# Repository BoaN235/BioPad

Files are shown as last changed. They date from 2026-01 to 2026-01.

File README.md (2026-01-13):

# BioPad
A 12 key macropad with a oled display and 5 LEDS uses KMK firmware. It is supposed to be a used during work to 

## Features
- 128x32 OLED Display
- KMK
- 12 Keys
- 4 Layers Currently
- 5 LEDS

## Cad Model
It fits with 4 M3 Bolts and it has 4 M1 Bolts to hold the pcb down. 
It has 3 parts the bottem the layer blocking the keys and top. 



## PCB
My PCB is 100mm by 58mm. I made it in Kicad



## Firmware
I am using KMK to be able to hotswitch it to whatever people need.
There is currently 3 layers Apps Vscode and Zoom. Each of those has hotkeys related to each app. The Apps layer types in Windows + R and adds the name of a website or app.

## BOM
Evreything I am gonna use to make it if it isen't in the kit I have it myself

- 12x Cherry MX Switches
- 12x DSA Keycaps
- 4x M3x5x4 Heatset inserts
- 4x M3x16mm SHCS Bolts
- 4x M1x5x4 Heatset inserts
- 4x M1x16mm SHCS Bolts
- 12x 1N4148 DO-35 Diodes.
- 5x WS2812B LEDs
- 1x 0.91" 128x32 OLED Display
- 1x XIAO RP2040
- 1x Case (3 printed parts I can print it myself)

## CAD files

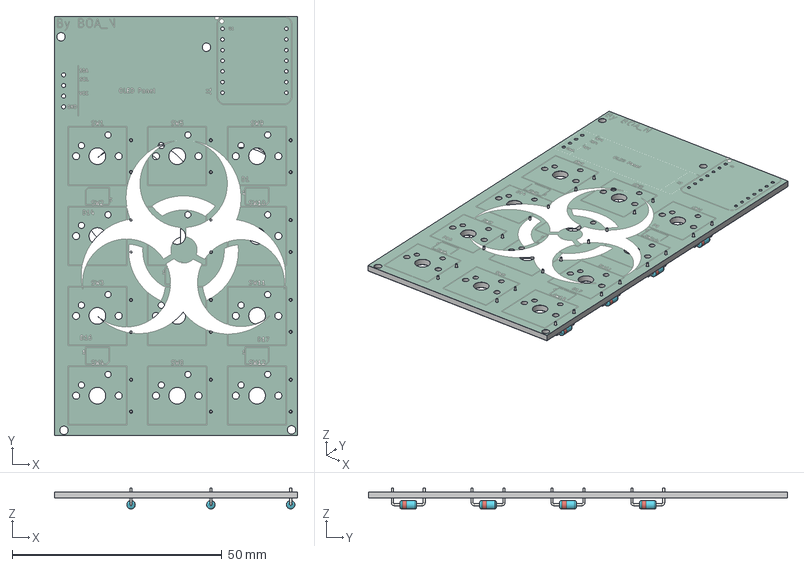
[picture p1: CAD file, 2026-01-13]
CAD/BioPad.step
58.0 x 100.0 x 5.01 mm
D_DO-35_SOD27_P7.62mm_Horizontal x 12
BioPad_silkscreen x 2
BioPad_soldermask x 2
BioPad_PCB

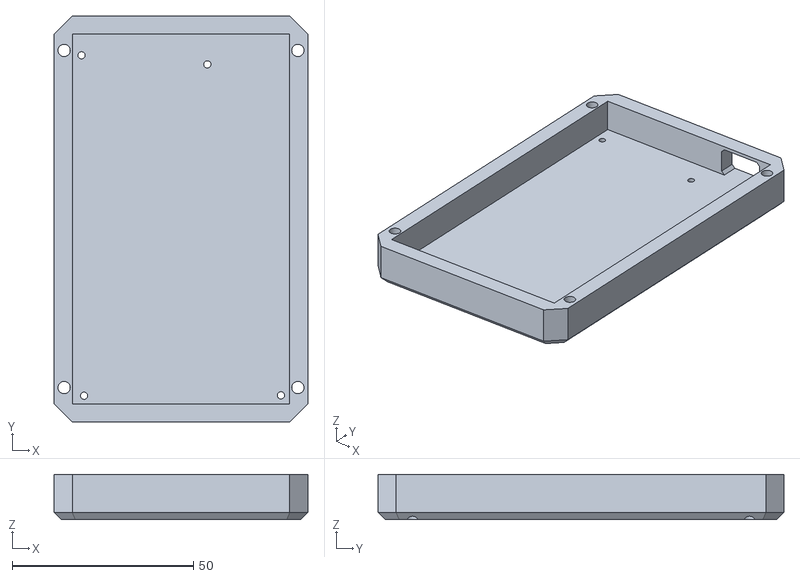
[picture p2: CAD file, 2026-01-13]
CAD/BaseHackPad.stl
70.0 x 112.0 x 12.5

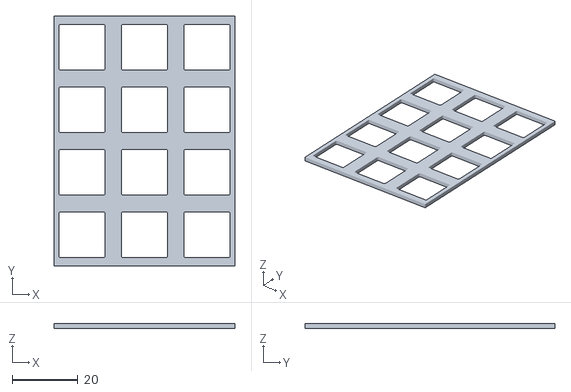
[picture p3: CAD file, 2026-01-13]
CAD/LayerHackPad.stl
55.1 x 76.2 x 1.50

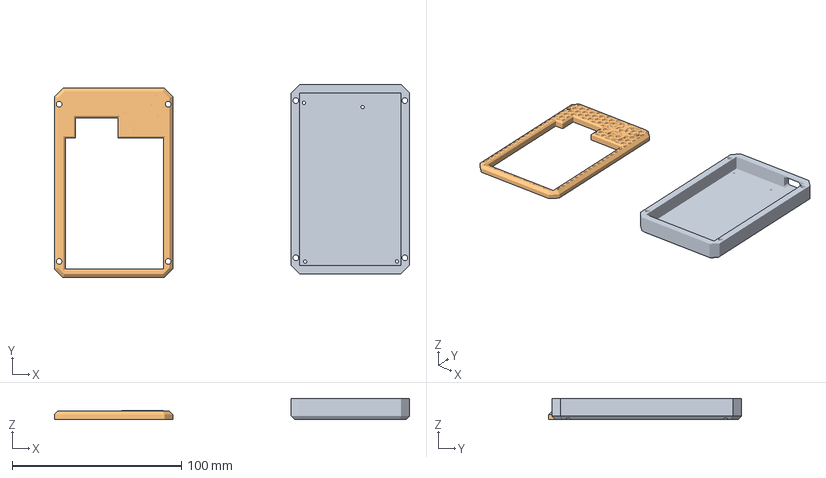
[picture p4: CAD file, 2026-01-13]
CAD/TopHackPad.3mf
210.0 x 114.1 x 12.5 mm
BaseHackPad.stl
TopHackPad.stl

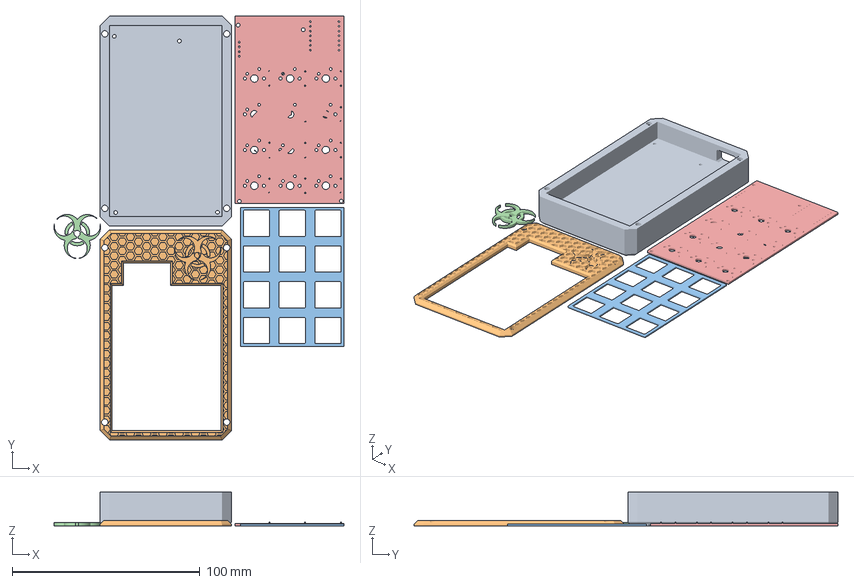
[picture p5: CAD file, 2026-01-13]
CAD/HackPad.3mf
154.5 x 226.0 x 18.0 mm
BaseHackPad.stl
TopHackPad.stl
LayerHackPad.stl
BioMedel.stl
PCBMesh.stl_B

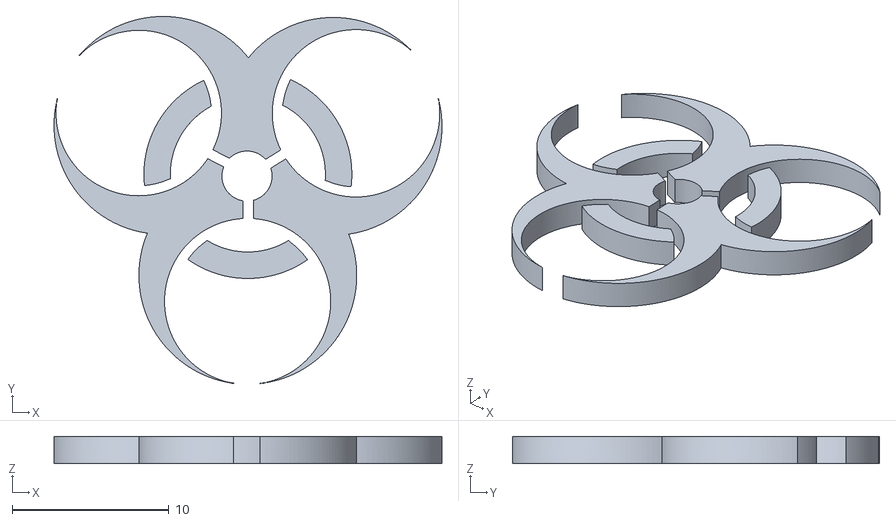
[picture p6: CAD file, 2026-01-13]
CAD/BioMedel.stl
24.8 x 23.4 x 1.75

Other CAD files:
CAD/PCBMesh.stl
CAD/TopHackPad.stl

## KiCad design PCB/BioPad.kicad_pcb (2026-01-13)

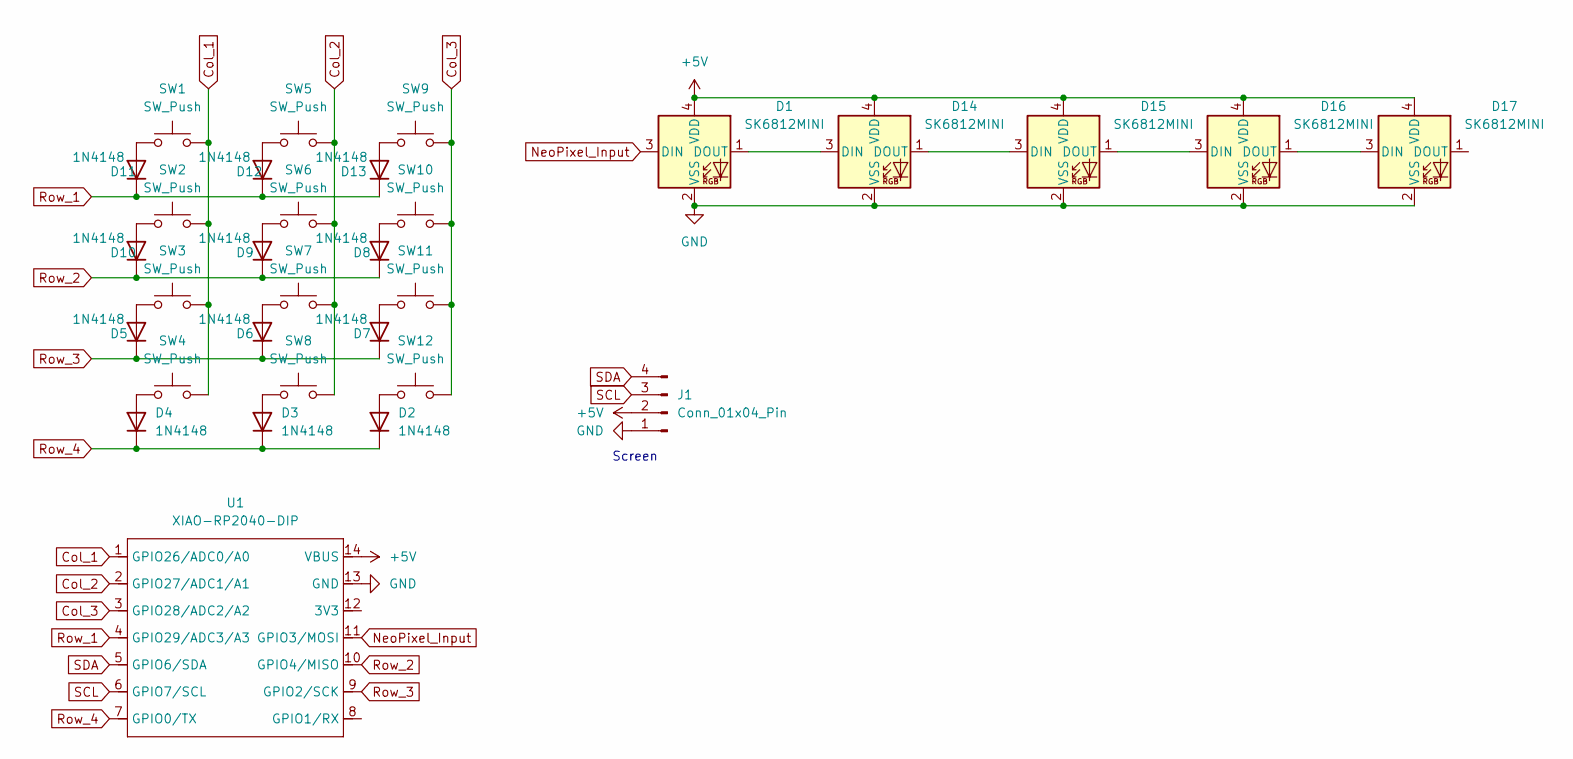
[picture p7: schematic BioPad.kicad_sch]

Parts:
D1, D14, D15, D16, D17: SK6812MINI; LED_SK6812MINI_PLCC4_3.5x3.5mm_P1.75mm
D2, D3, D4, D5, D6, D7, D8, D9, D10, D11, D12, D13: 1N4148; D_DO-35_SOD27_P7.62mm_Horizontal
J1: Conn_01x04_Pin; SSD1306-0.91-OLED-4pin-128x32
SW1, SW2, SW3, SW4, SW5, SW6, SW7, SW8, SW9, SW10, SW11, SW12: SW_Push; SW_Cherry_MX_1.00u_PCB
U1: XIAO-RP2040-DIP

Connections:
+5V: D1.4 (VDD), D14.4 (VDD), D15.4 (VDD), D16.4 (VDD), D17.4 (VDD), J1.2, U1.14 (VBUS)
Col_1: SW1.2, SW2.2, SW3.2, SW4.2, U1.1 (GPIO26/ADC0/A0)
Col_2: SW5.2, SW6.2, SW7.2, SW8.2, U1.2 (GPIO27/ADC1/A1)
Col_3: SW9.2, SW10.2, SW11.2, SW12.2, U1.3 (GPIO28/ADC2/A2)
GND: D1.2 (VSS), D14.2 (VSS), D15.2 (VSS), D16.2 (VSS), D17.2 (VSS), J1.1, U1.13 (GND)
NeoPixel_Input: D1.3 (DIN), U1.11 (GPIO3/MOSI)
unnamed: D1.1 (DOUT), D14.3 (DIN)
unnamed: D2.2 (A), SW12.1
unnamed: D3.2 (A), SW8.1
unnamed: D4.2 (A), SW4.1
unnamed: D5.2 (A), SW3.1
unnamed: D6.2 (A), SW7.1
unnamed: D7.2 (A), SW11.1
unnamed: D8.2 (A), SW10.1
unnamed: D9.2 (A), SW6.1
unnamed: D10.2 (A), SW2.1
unnamed: D11.2 (A), SW1.1
unnamed: D12.2 (A), SW5.1
unnamed: D13.2 (A), SW9.1
unnamed: D14.1 (DOUT), D15.3 (DIN)
unnamed: D15.1 (DOUT), D16.3 (DIN)
unnamed: D16.1 (DOUT), D17.3 (DIN)
Row_1: D11.1 (K), D12.1 (K), D13.1 (K), U1.4 (GPIO29/ADC3/A3)
Row_2: D8.1 (K), D9.1 (K), D10.1 (K), U1.10 (GPIO4/MISO)
Row_3: D5.1 (K), D6.1 (K), D7.1 (K), U1.9 (GPIO2/SCK)
Row_4: D2.1 (K), D3.1 (K), D4.1 (K), U1.7 (GPIO0/TX)
SCL: J1.3, U1.6 (GPIO7/SCL)
SDA: J1.4, U1.5 (GPIO6/SDA)

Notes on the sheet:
Screen

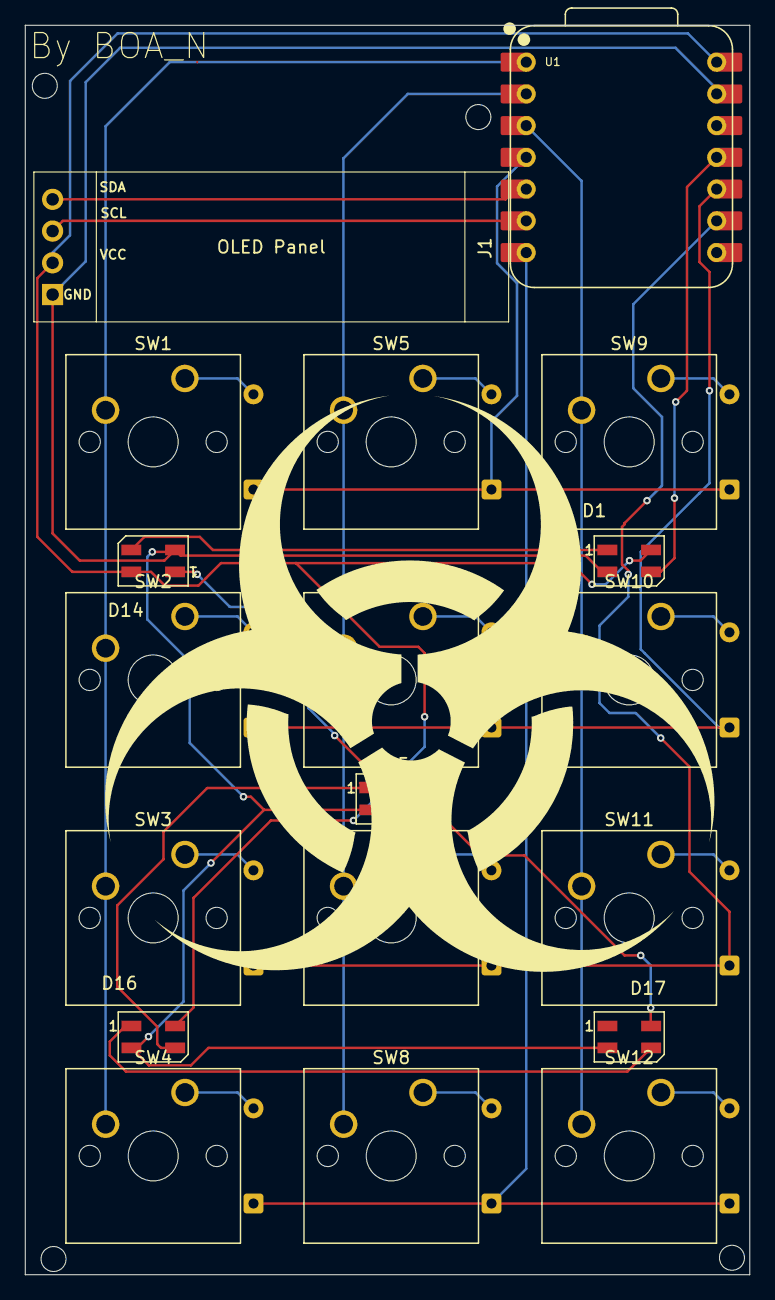
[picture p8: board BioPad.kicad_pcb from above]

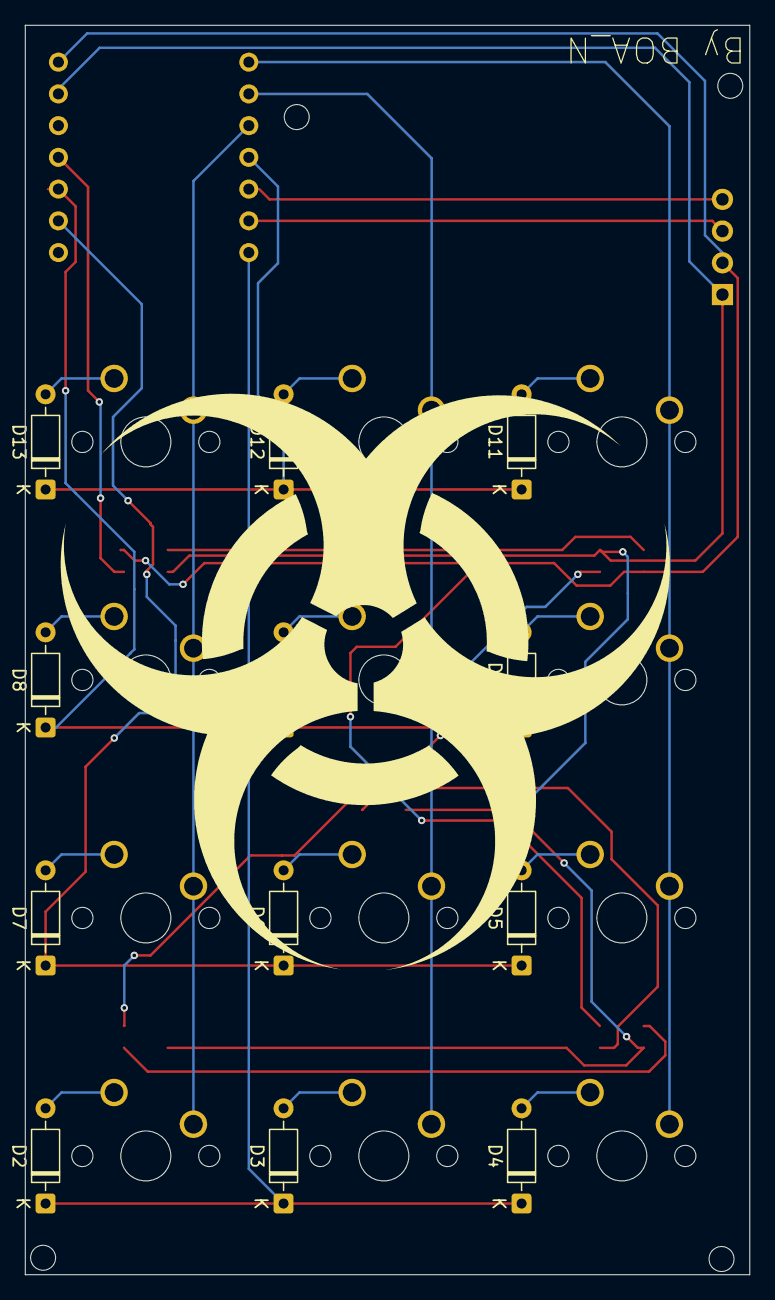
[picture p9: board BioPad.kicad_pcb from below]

Board: 2 copper layers, 58.0 x 100.0 mm, 31 parts (12 on the bottom side), 28 nets.

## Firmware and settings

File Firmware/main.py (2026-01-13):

print("Starting")

import board
import busio

from kmk.kmk_keyboard import KMKKeyboard
from kmk.keys import KC
from kmk.scanners import DiodeOrientation
from kmk.modules.layers import Layers
from kmk.modules.macros import Macros

from kmk.extensions.display import Display
from kmk.extensions.display.ssd1306 import SSD1306

keyboard = KMKKeyboard()

keyboard.col_pins = (board.GP26, board.GP27, board.GP28)
keyboard.row_pins = (board.GP29, board.GP4, board.GP2, board.GP0)
keyboard.diode_orientation = DiodeOrientation.COL2ROW


layers = Layers()
macros = Macros()

keyboard.modules.append(layers)
keyboard.modules.append(macros)


i2c = busio.I2C(board.GP7, board.GP6)

oled = SSD1306(
    i2c=i2c,
    width=128,
    height=32,
    rotation=0,
)

display = Display(
    display=oled,
    width=128,
    height=32,
    brightness=1,
)

keyboard.extensions.append(display)


LAYER_NAMES = {
    0: "BASE",
    1: "APPS",
    2: "ZOOM",
    3: "VSCODE",
}

def draw_layer(oled, layer):
    oled.fill(0)
    oled.text("Reprint", 0, 0, 1)
    oled.text(LAYER_NAMES.get(layer, "???"), 0, 16, 1)
    oled.show()

def on_layer_change(layer):
    draw_layer(oled, layer)

layers.after_layer_change = on_layer_change
draw_layer(oled, 0)


macros.macros = {
    # App Launch 
    "GMAIL": [KC.LGUI, KC.R, "https://mail.google.com", KC.ENTER],
    "CAL":   [KC.LGUI, KC.R, "https://calendar.google.com", KC.ENTER],
    "GIT":   [KC.LGUI, KC.R, "https://github.com", KC.ENTER],
    "JIRA":  [KC.LGUI, KC.R, "https://jira.atlassian.com", KC.ENTER],
    "ZOOM":  [KC.LGUI, KC.R, "zoom", KC.ENTER],
    "SLACK": [KC.LGUI, KC.R, "slack", KC.ENTER],
    "CODE":  [KC.LGUI, KC.R, "code", KC.ENTER],
    "EXP":   [KC.LGUI, KC.E],
    "LOCK":  [KC.LGUI, KC.L],

    # Zoom Controls
    "ZM_MUTE":  [KC.LALT, KC.A],
    "ZM_VIDEO": [KC.LALT, KC.V],
    "ZM_SHARE": [KC.LALT, KC.S],
    "ZM_FOCUS": [KC.LCTRL, KC.LALT, KC.LSHIFT],

    # VS Code
    "VS_CMD":   [KC.LCTRL, KC.LSHIFT, KC.P],
    "VS_OPEN":  [KC.LCTRL, KC.P],
    "VS_TERM":  [KC.LCTRL, KC.GRAVE],
    "VS_SAVE":  [KC.LCTRL, KC.S],
    "VS_FIND":  [KC.LCTRL, KC.F],
    "VS_REPL":  [KC.LCTRL, KC.H],
    "VS_FMT":   [KC.LSHIFT, KC.LALT, KC.F],
}


MO_APPS   = KC.MO(1)
MO_ZOOM   = KC.MO(2)
MO_VSCODE = KC.MO(3)

keyboard.keymap = [
    # Layer 0 — BASE
    [
        KC.A,       KC.B,       KC.C,
        KC.D,       KC.E,       KC.F,
        KC.G,       KC.H,       KC.I,
        MO_APPS,    MO_ZOOM,    MO_VSCODE,
    ],

    # Layer 1 — APPS
    [
        KC.MACRO("GMAIL"), KC.MACRO("CAL"),   KC.MACRO("GIT"),
        KC.MACRO("JIRA"),  KC.MACRO("ZOOM"),  KC.MACRO("SLACK"),
        KC.MACRO("CODE"),  KC.MACRO("EXP"),   KC.NO,
        KC.MACRO("LOCK"),  KC.NO,             KC.NO,
    ],

    # Layer 2 — ZOOM
    [
        KC.MACRO("ZM_MUTE"),  KC.MACRO("ZM_VIDEO"), KC.MACRO("ZM_SHARE"),
        KC.MACRO("ZM_FOCUS"), KC.NO,                KC.NO,
        KC.NO,                KC.NO,                KC.NO,
        KC.MO(0),             KC.NO,                KC.NO,
    ],

    # Layer 3 — VSCODE
    [
        KC.MACRO("VS_CMD"),  KC.MACRO("VS_OPEN"), KC.MACRO("VS_TERM"),
        KC.F12,              KC.MACRO("VS_FIND"), KC.MACRO("VS_REPL"),
        KC.MACRO("VS_SAVE"), KC.MACRO("VS_FMT"),  KC.NO,
        KC.MO(0),            KC.NO,               KC.NO,
    ],
]

if __name__ == "__main__":
    keyboard.go()

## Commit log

2026-01-13 init commit
    [BaseHackPad.stl, BioMedel.stl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]
2026-01-13 Add initial README for BioPad project
    Added detailed information about the BioPad project, including features, CAD model, PCB specifications, firmware, and bill of materials.
